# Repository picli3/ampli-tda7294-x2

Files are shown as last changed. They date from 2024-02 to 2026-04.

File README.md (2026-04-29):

# ampli-tda7294-x2

Amplificador de audio basado en **dos TDA7294**, pensado como una solución práctica para construir una etapa estéreo de potencia usando un integrado muy conocido en audio DIY.

## Propósito del proyecto
Este repositorio reúne el diseño electrónico y mecánico de una placa orientada a implementar un amplificador con **dos canales**, usando el TDA7294 como núcleo de cada etapa.

La idea principal del proyecto es ofrecer una base para:
- construir un amplificador estéreo
- reutilizar una topología conocida y fácil de conseguir
- integrar PCB, esquemático y soporte mecánico/disipación
- facilitar prototipado o fabricación de una etapa de audio casera o semiprofesional

## Qué incluye
- esquemáticos del amplificador
- diseño PCB en KiCad
- documentación exportada en PDF/HTML
- archivos mecánicos del disipador o soporte en FreeCAD

## Enfoque técnico
El TDA7294 es un integrado muy usado en amplificadores de audio por su simplicidad de implementación y buena potencia para aplicaciones domésticas, educativas o DIY. En este proyecto se usa por duplicado, lo que permite montar una etapa de dos canales sobre una misma base de diseño.

## Aplicaciones típicas
- amplificador estéreo DIY
- sistema de audio casero
- etapa de potencia para pruebas de laboratorio
- proyecto educativo de audio analógico

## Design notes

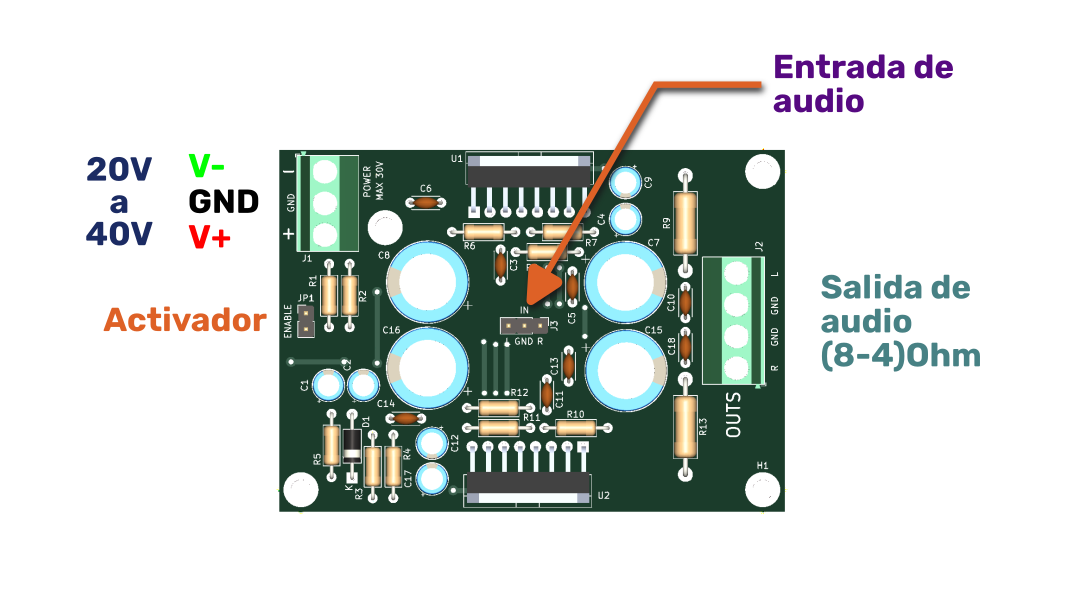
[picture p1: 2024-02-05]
doc/conexion.png

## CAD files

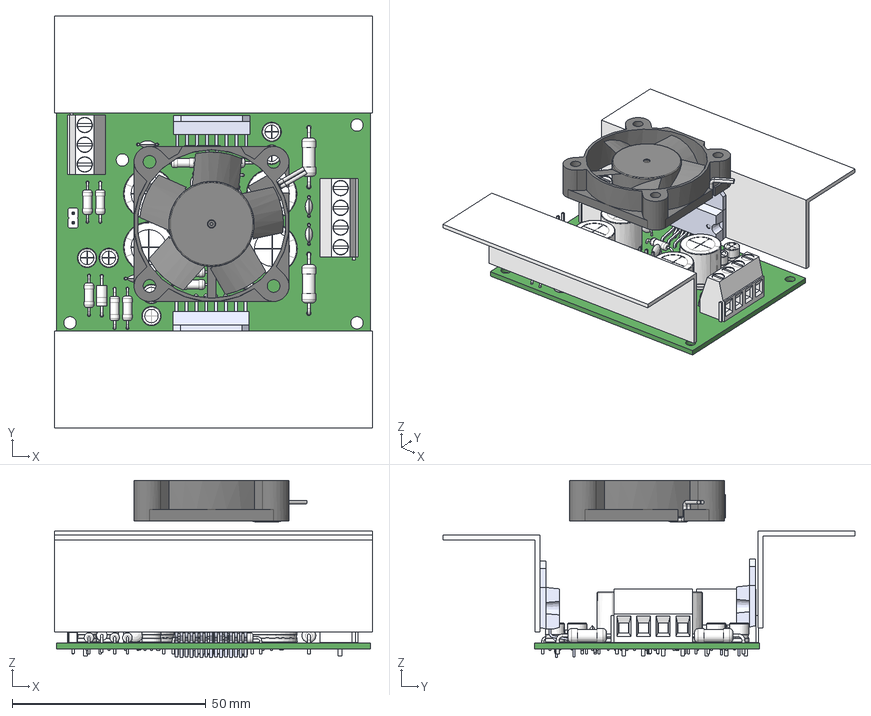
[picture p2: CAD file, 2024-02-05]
solid/cooler.FCStd
82.0 x 106.2 x 45.8 mm
TDA7294 PCB
40x40x10
40x40x011
40x40x012
blade

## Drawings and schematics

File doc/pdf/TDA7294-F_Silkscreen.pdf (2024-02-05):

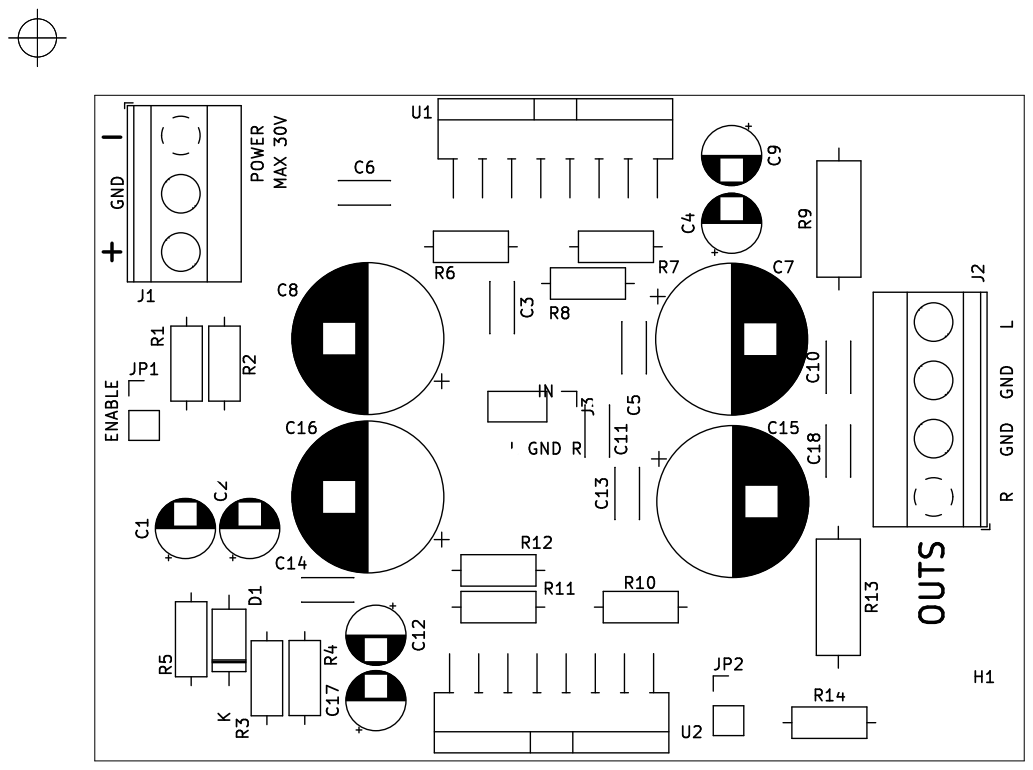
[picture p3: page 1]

OUTS R MAX 30V GND L - L GND R GND

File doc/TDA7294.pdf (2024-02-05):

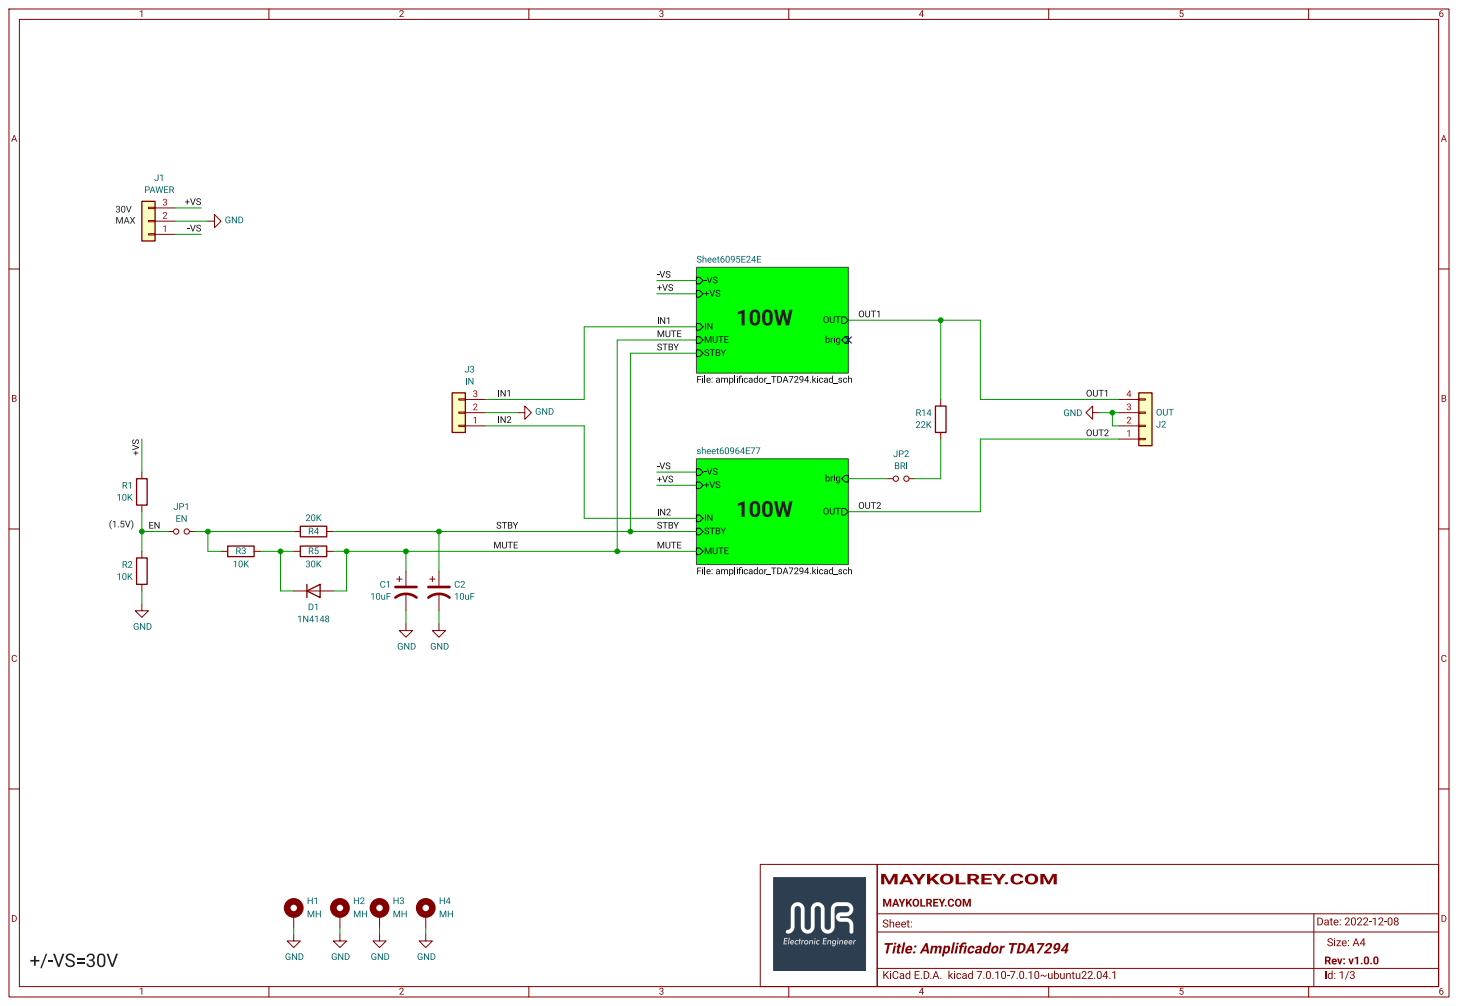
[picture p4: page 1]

Sheet: MAYKOLREY.COM MAYKOLREY.COM

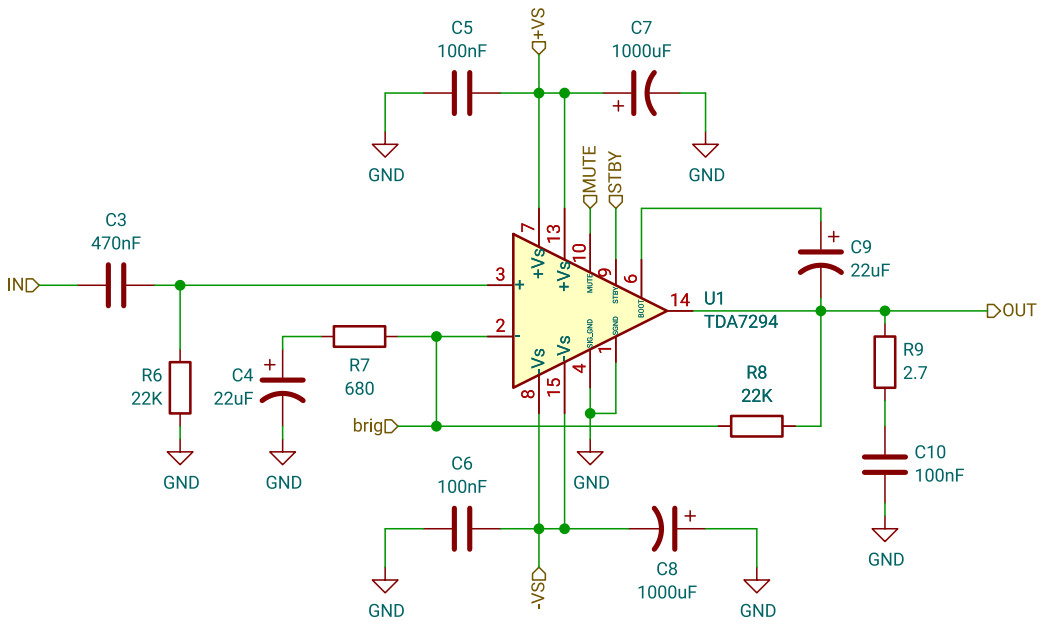
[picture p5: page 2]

Id: 2/3 Title: Sheet:Sheet6095E24E MAYKOLREY.COM

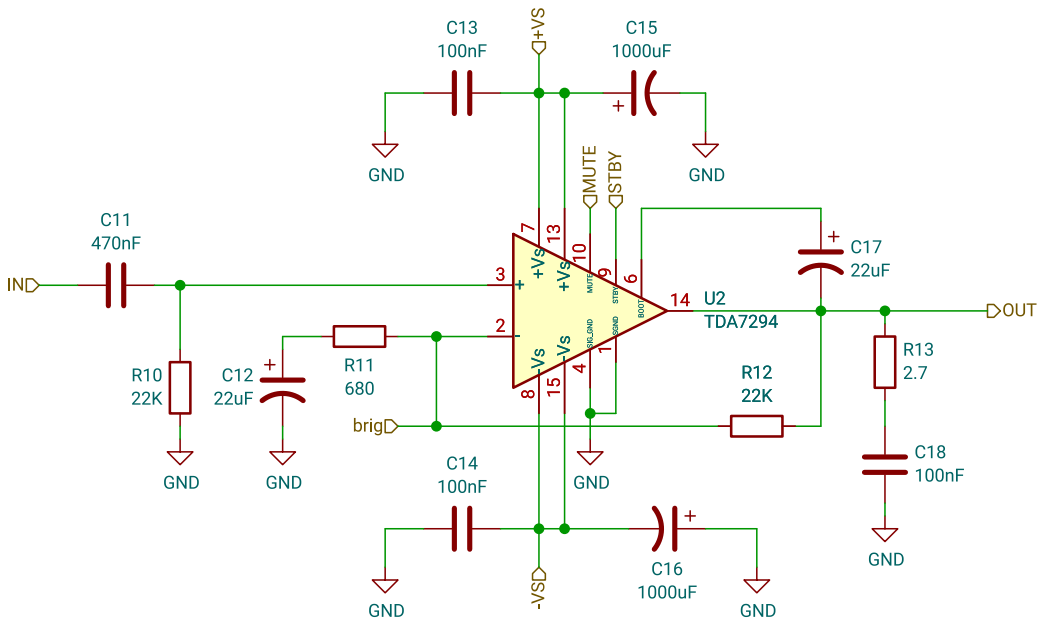
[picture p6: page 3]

Id: 3/3 Title: Sheet: sheet60964E77 MAYKOLREY.COM

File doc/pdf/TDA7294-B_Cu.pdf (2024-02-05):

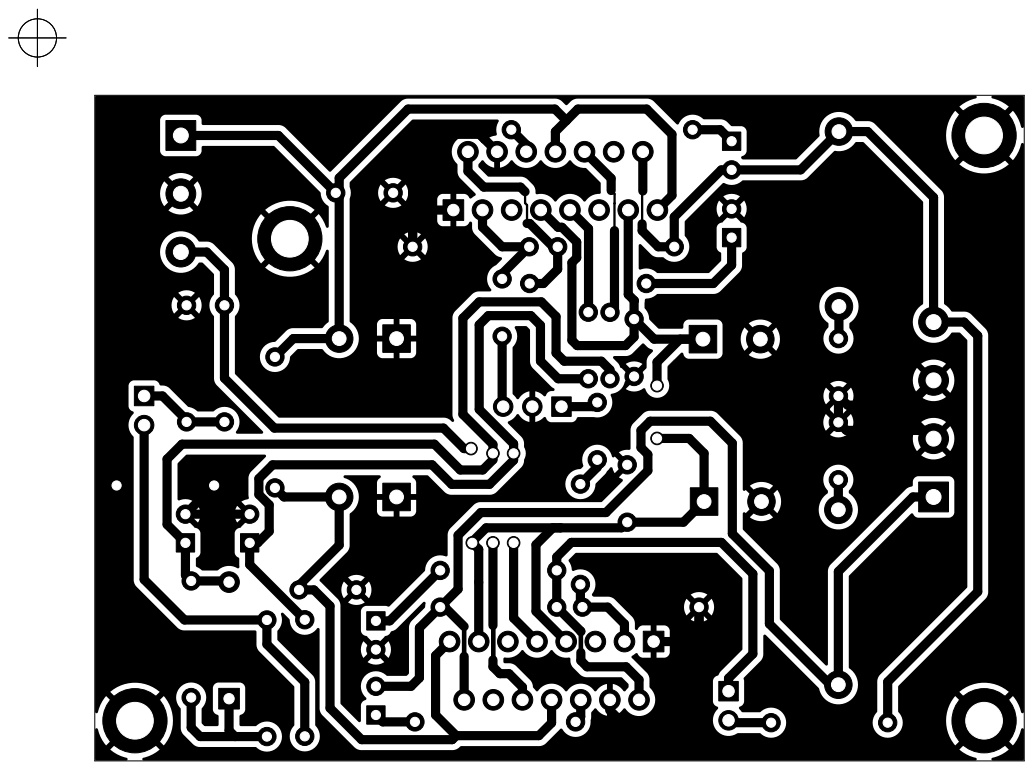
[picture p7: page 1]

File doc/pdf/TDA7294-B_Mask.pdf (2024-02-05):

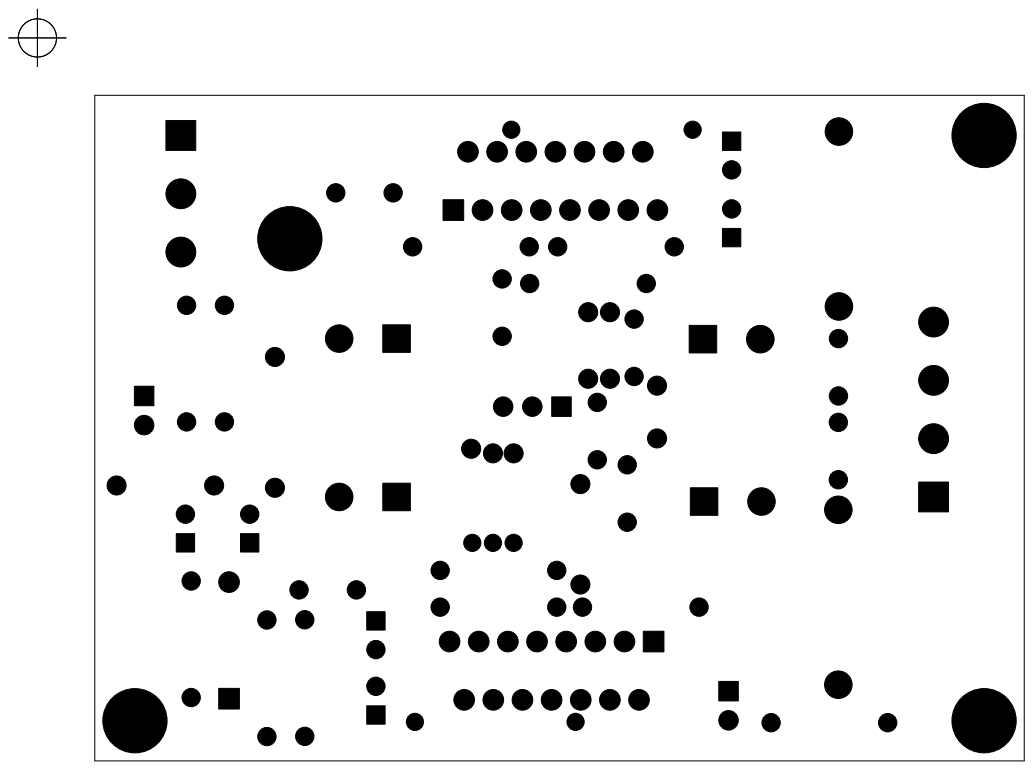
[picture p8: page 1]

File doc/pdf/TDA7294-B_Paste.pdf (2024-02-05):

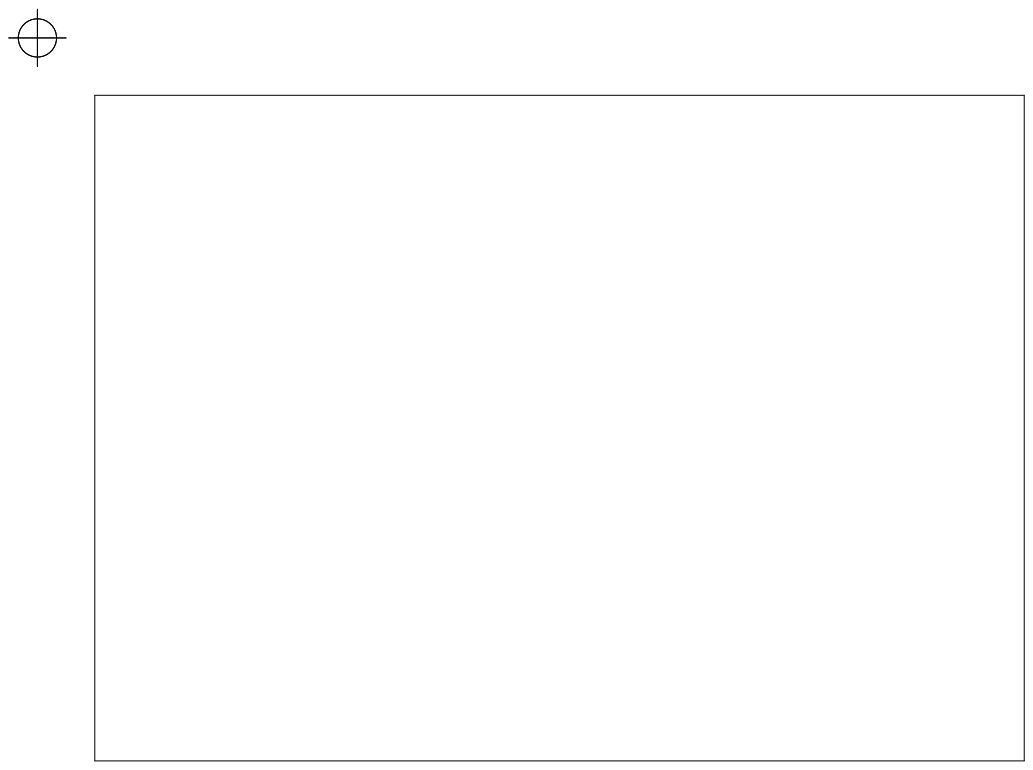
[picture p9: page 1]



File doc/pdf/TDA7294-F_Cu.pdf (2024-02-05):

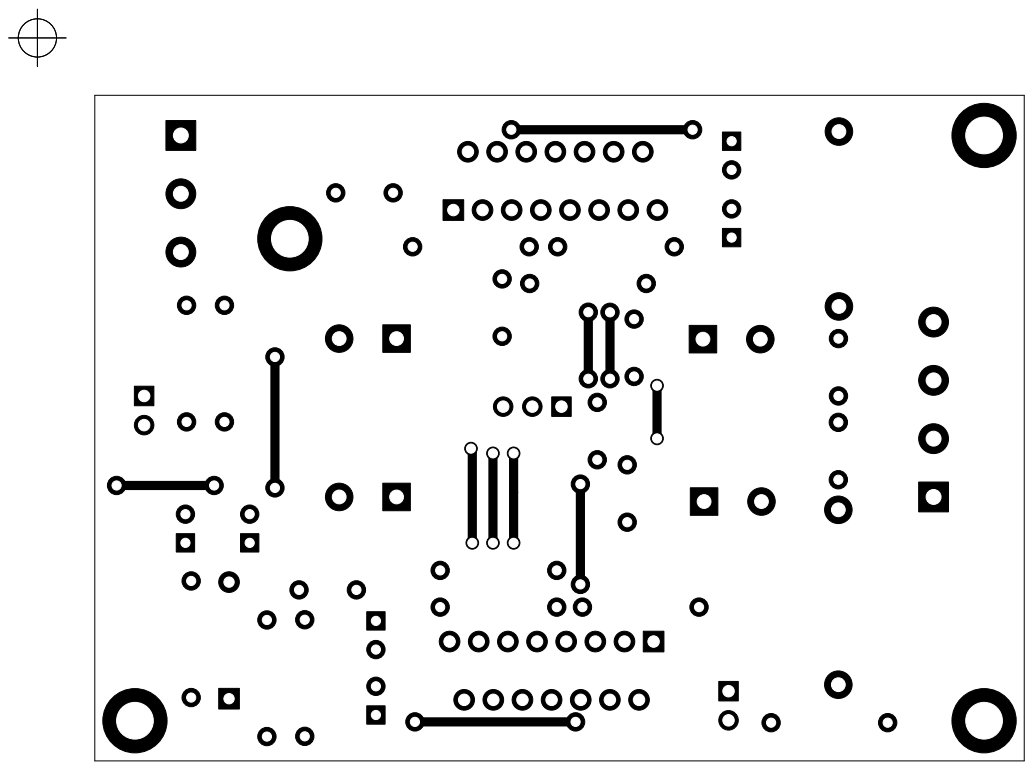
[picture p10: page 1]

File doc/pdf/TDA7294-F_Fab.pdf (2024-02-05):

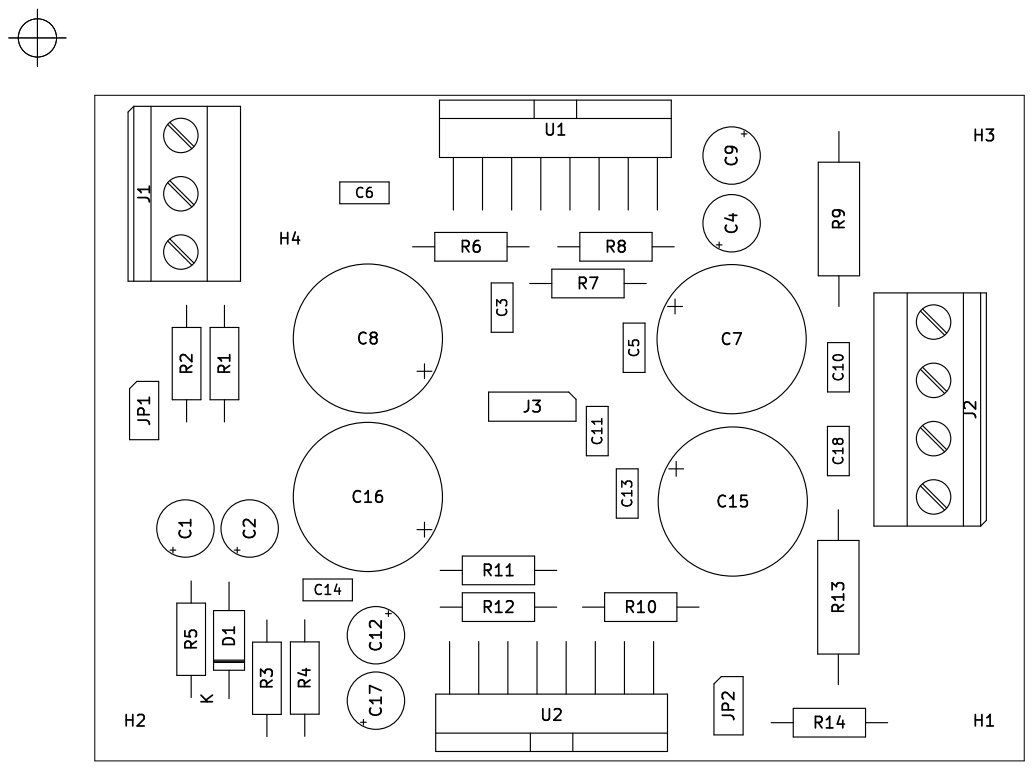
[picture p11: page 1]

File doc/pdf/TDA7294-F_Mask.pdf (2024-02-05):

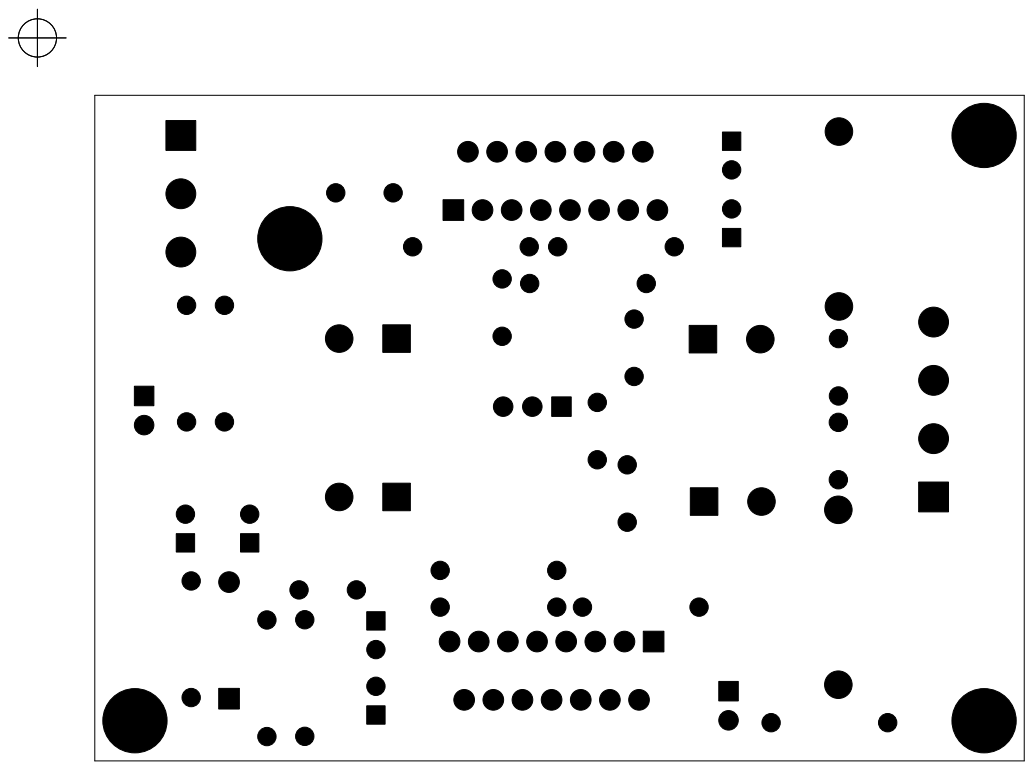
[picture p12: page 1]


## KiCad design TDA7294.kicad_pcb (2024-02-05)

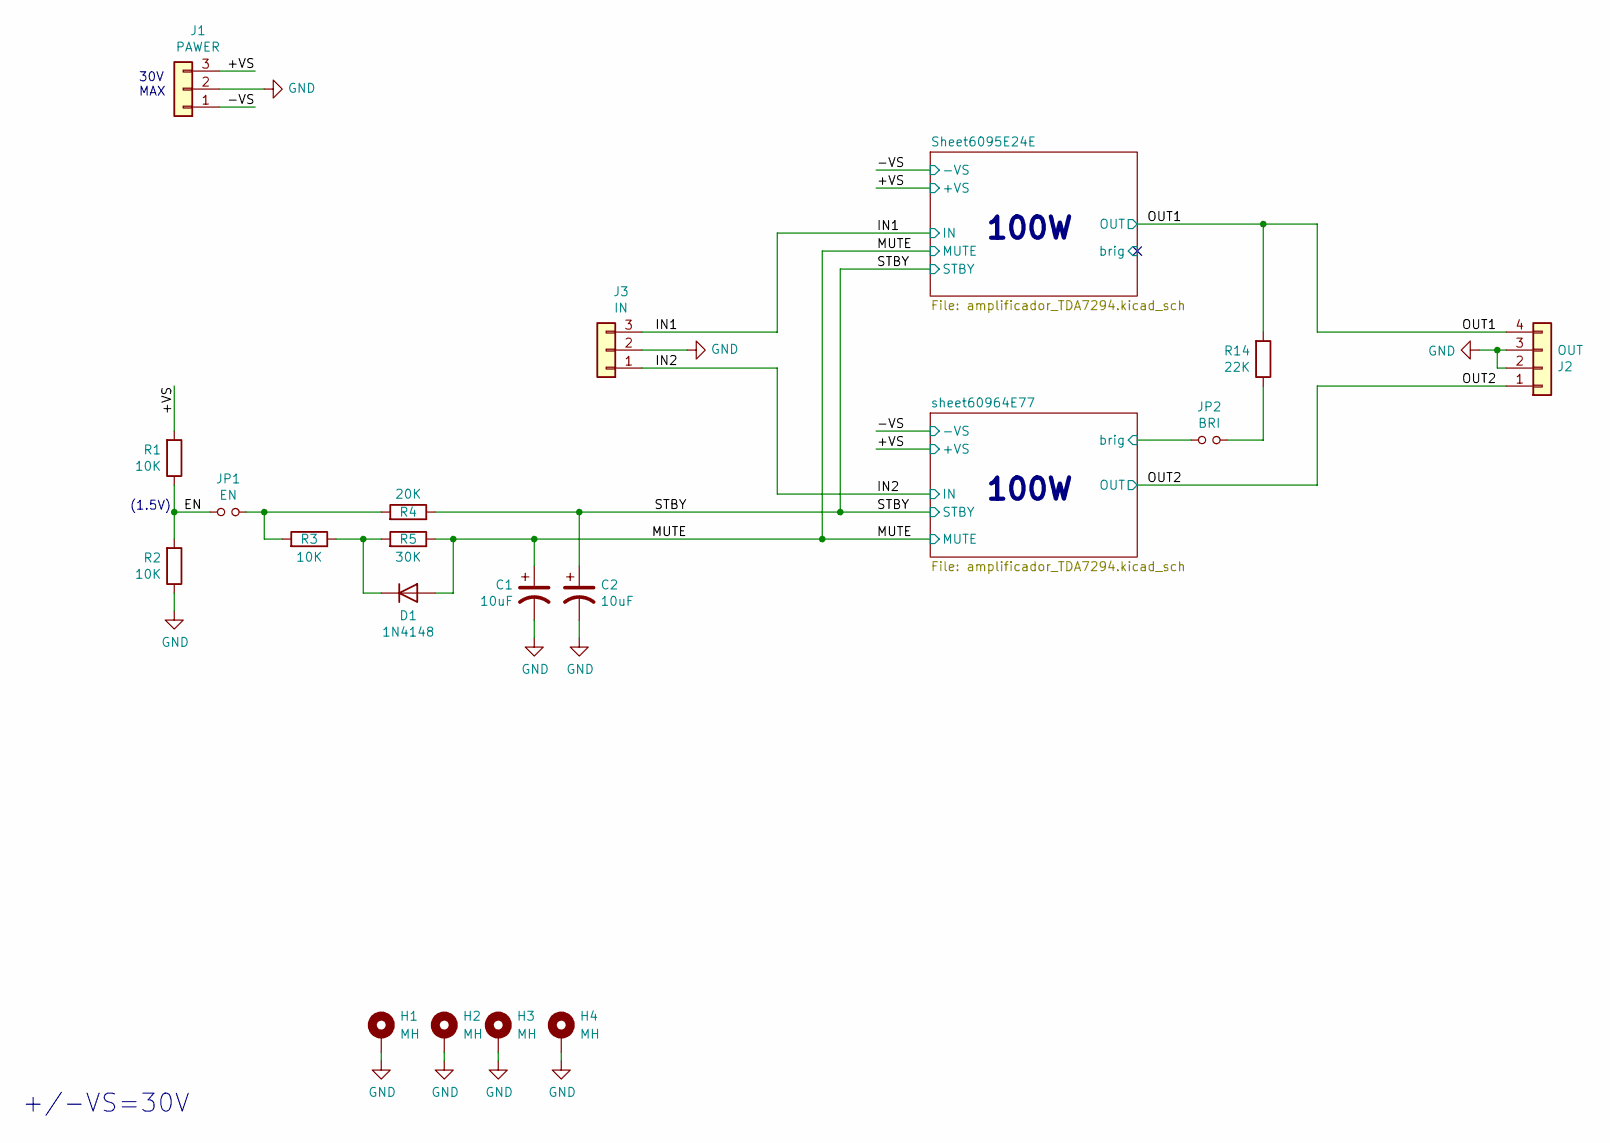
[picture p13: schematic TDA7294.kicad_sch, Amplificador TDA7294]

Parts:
C1, C2: 10uF; CP_Radial_D5.0mm_P2.50mm
D1: 1N4148; D_A-405_P10.16mm_Horizontal
H1, H2, H3, H4: MH; MountingHole_3.2mm_M3_DIN965_Pad
J1: PAWER; TerminalBlock_Phoenix_MKDS-1,5-3-5.08_1x03_P5.08mm_Horizont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
J2: OUT; TerminalBlock_Phoenix_MKDS-1,5-4-5.08_1x04_P5.08mm_Horizont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
J3: IN; PinHeader_1x03_P2.54mm_Vertical
JP1: EN; PinHeader_1x02_P2.54mm_Vertical
JP2: BRI; PinHeader_1x02_P2.54mm_Vertical
R1, R2, R3: 10K; R_Axial_DIN0207_L6.3mm_D2.5mm_P10.16mm_Horizontal
R4: 20K; R_Axial_DIN0207_L6.3mm_D2.5mm_P10.16mm_Horizontal
R5: 30K; R_Axial_DIN0207_L6.3mm_D2.5mm_P10.16mm_Horizontal
R14: 22K; R_Axial_DIN0207_L6.3mm_D2.5mm_P10.16mm_Horizontal

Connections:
/+VS: J1.3, R1.2; also elsewhere on the board
/-VS: J1.1; also elsewhere on the board
/EN: JP1.1, R1.1, R2.2
/IN1: J3.3; also elsewhere on the board
/IN2: J3.1; also elsewhere on the board
/MUTE: C1.1, D1.2 (A), R5.1; also elsewhere on the board
/OUT1: J2.4, R14.2; also elsewhere on the board
/OUT2: J2.1; also elsewhere on the board
/STBY: C2.1, R4.1; also elsewhere on the board
/sheet60964E77/brig: JP2.1; also elsewhere on the board
GND: C1.2, C2.2, H1.1, H2.1, H3.1, H4.1, J1.2, J2.2, J2.3, J3.2, R2.1; also elsewhere on the board
unnamed: D1.1 (K), R3.1, R5.2
unnamed: JP1.2, R3.2, R4.2
unnamed: JP2.2, R14.1

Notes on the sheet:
100W
+/-VS=30V
(1.5V)
30V MAX

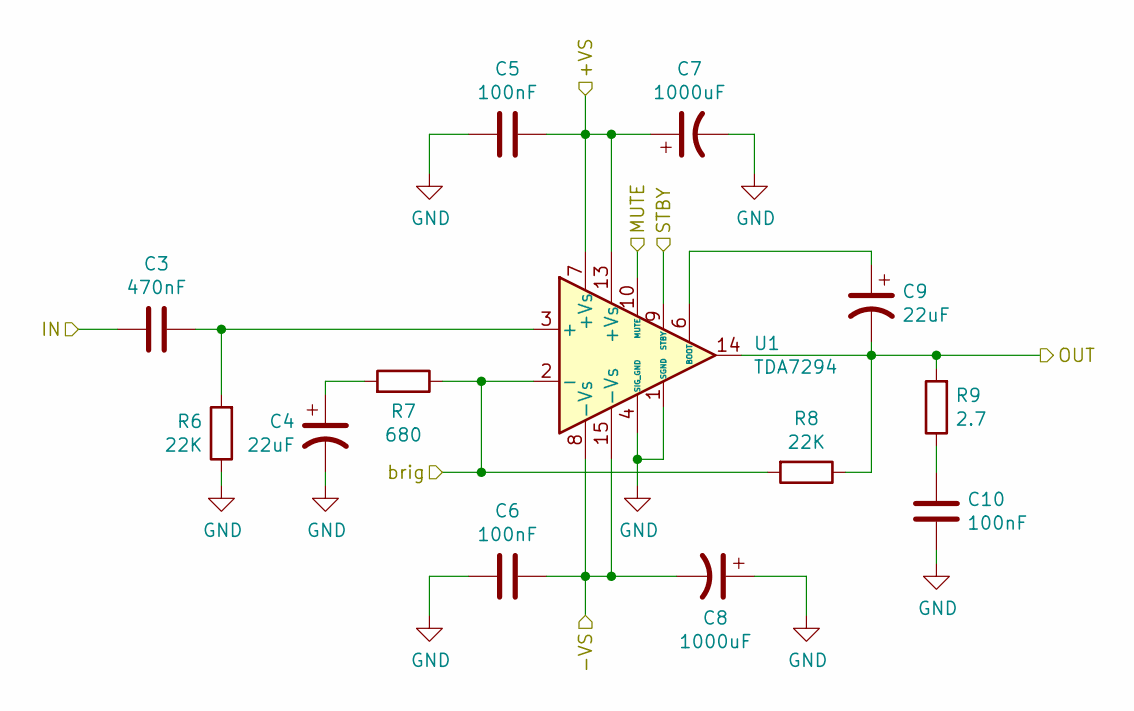
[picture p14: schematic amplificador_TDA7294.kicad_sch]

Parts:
C3: 470nF; C_Disc_D4.3mm_W1.9mm_P5.00mm
C4, C9: 22uF; CP_Radial_D5.0mm_P2.50mm
C5, C6, C10: 100nF; C_Disc_D4.3mm_W1.9mm_P5.00mm
C7, C8: 1000uF; CP_Radial_D13.0mm_P5.00mm
R6, R8: 22K; R_Axial_DIN0207_L6.3mm_D2.5mm_P10.16mm_Horizontal
R7: 680; R_Axial_DIN0207_L6.3mm_D2.5mm_P10.16mm_Horizontal
R9: 2.7; R_Axial_DIN0411_L9.9mm_D3.6mm_P15.24mm_Horizontal
U1: TDA7294; TO-220-15_P2.54x2.54mm_StaggerOdd_Lead4.58mm_Vertical

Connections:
/+VS: C5.1, C7.1, U1.7 (+Vs), U1.13 (+Vs); also elsewhere on the board
/-VS: C6.1, C8.2, U1.8 (-Vs), U1.15 (-Vs); also elsewhere on the board
/IN1: C3.2; also elsewhere on the board
/MUTE: U1.10 (MUTE); also elsewhere on the board
/OUT1: C9.2, R8.1, R9.2, U1.14; also elsewhere on the board
/STBY: U1.9 (STBY); also elsewhere on the board
/Sheet6095E24E/brig: R7.1, R8.2, U1.2 (-)
GND: C4.2, C5.2, C6.2, C7.2, C8.1, C10.1, R6.1, U1.1 (SGND), U1.4 (SIG_GND); also elsewhere on the board
unnamed: C4.1, R7.2
unnamed: C10.2, R9.1
unnamed: C3.1, R6.2, U1.3 (+)
unnamed: C9.1, U1.6 (BOOT)

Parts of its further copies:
C11: 470nF; C_Disc_D4.3mm_W1.9mm_P5.00mm
C12, C17: 22uF; CP_Radial_D5.0mm_P2.50mm
C13, C14, C18: 100nF; C_Disc_D4.3mm_W1.9mm_P5.00mm
C15, C16: 1000uF; CP_Radial_D13.0mm_P5.00mm
R10, R12: 22K; R_Axial_DIN0207_L6.3mm_D2.5mm_P10.16mm_Horizontal
R11: 680; R_Axial_DIN0207_L6.3mm_D2.5mm_P10.16mm_Horizontal
R13: 2.7; R_Axial_DIN0411_L9.9mm_D3.6mm_P15.24mm_Horizontal
U2: TDA7294; TO-220-15_P2.54x2.54mm_StaggerOdd_Lead4.58mm_Vertical

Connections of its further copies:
/+VS: C13.1, C15.1, U2.7 (+Vs), U2.13 (+Vs); also elsewhere on the board
/-VS: C14.1, C16.2, U2.8 (-Vs), U2.15 (-Vs); also elsewhere on the board
/IN2: C11.2; also elsewhere on the board
/MUTE: U2.10 (MUTE); also elsewhere on the board
/OUT2: C17.2, R12.1, R13.2, U2.14; also elsewhere on the board
/STBY: U2.9 (STBY); also elsewhere on the board
/sheet60964E77/brig: R11.1, R12.2, U2.2 (-); also elsewhere on the board
GND: C12.2, C13.2, C14.2, C15.2, C16.1, C18.1, R10.1, U2.1 (SGND), U2.4 (SIG_GND); also elsewhere on the board
unnamed: C12.1, R11.2
unnamed: C18.2, R13.1
unnamed: C11.1, R10.2, U2.3 (+)
unnamed: C17.1, U2.6 (BOOT)

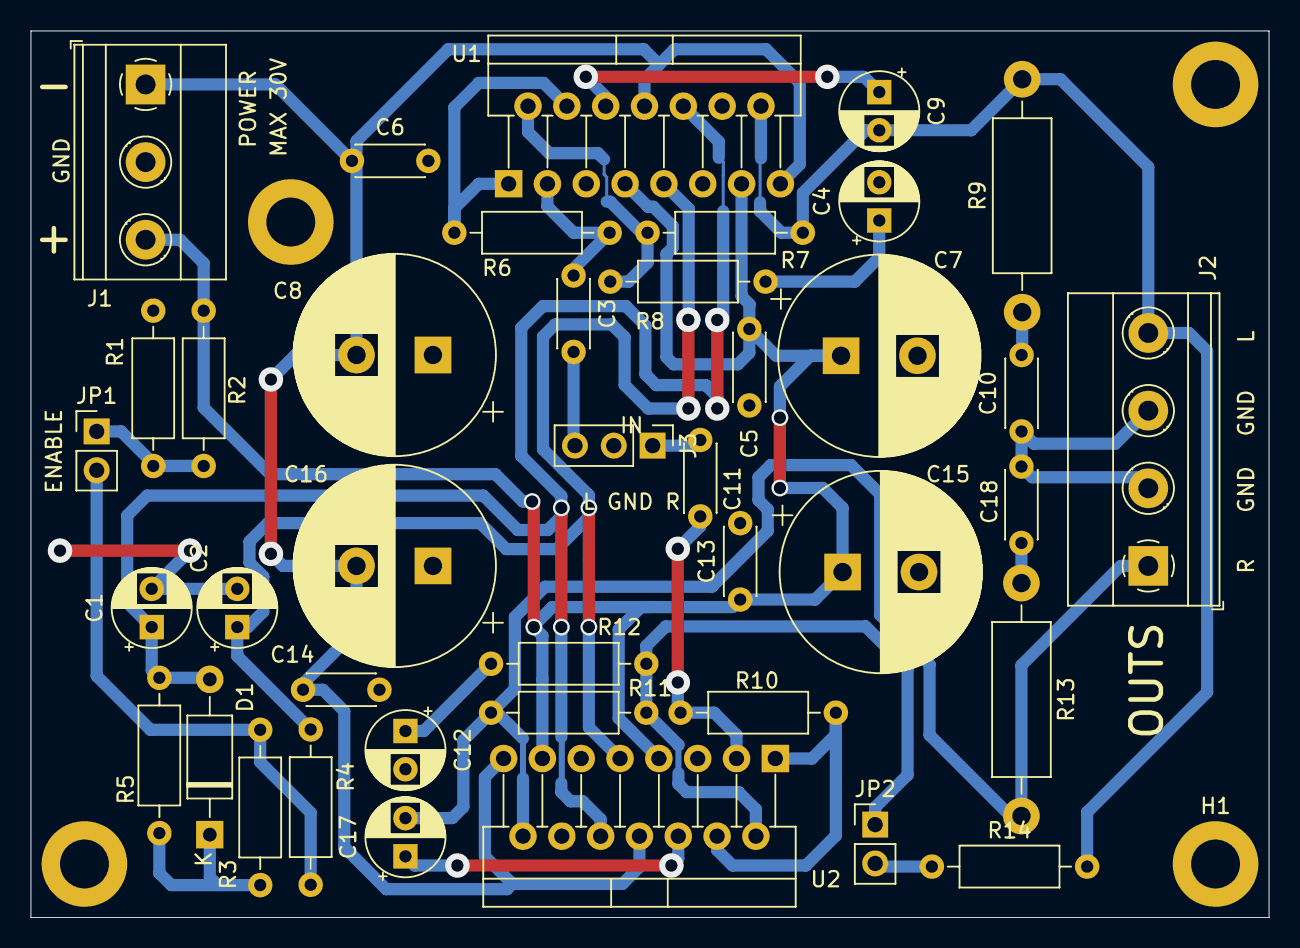
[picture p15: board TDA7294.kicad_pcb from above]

Board: 2 copper layers, 81.0 x 58.0 mm, 44 parts (0 on the bottom side), 23 nets.

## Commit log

2022-06-05 enviado a fabricar
    [TDA7294-B_Cu.gbr, TDA7294-B_Mask.gbr, TDA7294-B_Paste.gbr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]
2022-12-08 agregando huecos para montaje
    [TDA7294-B_Cu.gbr, TDA7294-B_Mask.gbr, TDA7294-B_Paste.gbr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]
2024-02-05 add version puenteable y archivos en pdf
    [TDA7294-B_Cu.gbr, TDA7294-B_Mask.gbr, TDA7294-B_Paste.gbr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]
